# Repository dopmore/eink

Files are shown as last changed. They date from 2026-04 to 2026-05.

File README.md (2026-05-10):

Tiny e-reader

# Tiny-e-ink-Ebook-reader
This project aims to create a small portable e-reader, using an E-ink Display and a SD-card for storage.
It includes a Multi Directional Switch and a Select Button for inputs. While the MDS is for navigation (Next Page / Last Page), the select button is used to make a book mark and the middle button of the MDS then can be used to go back to the saved bookmark. 

I wanted to make this to be able to read books anywhere at any time without needing to carry around a big e-reader or get distracted by my phone :)!

## CAD / Assembly



The Assembly is easy as the case consists of only two parts that slide into each other and trap the PCB + Battery in between.

## PCB
eink2



The PCB will be soldered using a hotplate.

## Schematics


## PCB-order:


## Parts (LCSC):


## BOM
| Component | Link / Company | Price | Shipping | 
| ---- | ---- | ---- | ---- |
| PCB + Stencil | jlcpcb.com | $12.44 | free (coupon) |
| PCB-Parts  | lcsc.com | $15.42 | $8.95 |
| 103450 3,7 V 1500 mAh Polymer-Lithium-Akku jst PH 2,0 mm | https://www.aliexpress.com/item/1005009590723370.html | $7.60 | free |
| E-paper Screen 296x128 (GDEY029T94) | https://buy-lcd.com/products/29-inch-e-paper-screen-296x128-raspberry-pi-spi-display-gdey029t94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 | $7.91 | $10 |

Total: 62.32 (Incl. Shipping)

## Parts-Bom

| Index | LCSC# | MPN | Manufacturer | Package | Customer # | Description | RoHS | Quantity | MOQ | Multiple | Unit Price ($) | Extended Price ($) | Product Link |
| ----- | --- | --- | --- | --- | --- | --- | ---- | --- | --- | --- | --- | --- | --- |
| 1 | C325532 | RMC04022.21%N | TyoHM | 0402 | | 2.2Ω ±1% 62.5mW 0402 Thick Film Resistor | yes  | 100 | 100 | 100 | 0.0034 | 0.34 | [https://www.lcsc.com/product-detail/C325532.html](https://www.lcsc.com/product-detail/C325532.html) |
| 2 | C71911 | 16-213SDRC/S530-A3/TR8 | EVERLIGHT | 0402 | | Red 650nm LED Indication - Discrete 2V 0402 | yes  | 20 | 20  | 20 | 0.0330 | 0.66 | [https://www.lcsc.com/product-detail/C71911.html](https://www.lcsc.com/product-detail/C71911.html) |
| 3 | C77336 | MBR0530 | JSCJ | SOD-123 | | Diode 30V 500mA Surface Mount SOD-123 | yes  | 20 | 20  | 20 | 0.0332 | 0.66 | [https://www.lcsc.com/product-detail/C77336.html](https://www.lcsc.com/product-detail/C77336.html) |
| 4 | C7603347  | SI1308EDL | TECH PUBLIC | SOT-323 | | 30V 1.4A 360mW Surface Mount SOT-323 | yes  | 5 | 5 | 5 | 0.0840 | 0.42 | [https://www.lcsc.com/product-detail/C7603347.html](https://www.lcsc.com/product-detail/C7603347.html) |
| 5 | C52923 | CL05A105KA5NQNC | Samsung Electro-Mechanics | 0402 | | 1uF ±10% 25V Ceramic Capacitor X5R 0402 | yes  | 100 | 100 | 100 | 0.0040 | 0.40 | [https://www.lcsc.com/product-detail/C52923.html](https://www.lcsc.com/product-detail/C52923.html) |
| 6 | C511277 | MCP1700-3302E/TO | MICROCHIP | TO-92-3 | | 3.3V Positive Fixed TO-92-3 Voltage Regulators - Linear, Low Drop Out (LDO) Regulators RoHS | yes  | 1 | 1 | 1 | 0.8030 | 0.80 | [https://www.lcsc.com/product-detail/C511277.html](https://www.lcsc.com/product-detail/C511277.html) |
| 7 | C481407 | NX3225GA-12MHZ-STD-CRG-2 | NDK | SMD3225-4P | | Crystal 12MHz ±20ppm 8pF 100Ω SMD3225-4P | yes  | 5 | 5 | 5 | 0.2377 | 1.19 | [https://www.lcsc.com/product-detail/C481407.html](https://www.lcsc.com/product-detail/C481407.html) |
| 8 | C47647 | PH-2P | BOOMELE(Boom Precision Elec) | SMD,P=2mm,Surface Mount,Right Angle | | Connector Header 2 position 2mm Pitch Surface Mount, Right Angle | yes  | 12 | 12  | 12 | 0.0614 | 0.74 | [https://www.lcsc.com/product-detail/C47647.html](https://www.lcsc.com/product-detail/C47647.html) |
| 9 | C424093 | MCP73831T-2ACI/OT | MICROCHIP | SOT-23-5 | | 3.75V~6V Lithium Battery 1 550mA SOT-23-5 Battery Chargers ICs RoHS | yes  | 1 | 1 | 1 | 0.7611 | 0.76 | [https://www.lcsc.com/product-detail/C424093.html](https://www.lcsc.com/product-detail/C424093.html) |
| 10 | C4109 | 0402WGF2001TCE | UNI-ROYAL | 0402 | | 2kΩ ±1% 62.5mW 0402 Thick Film Resistor | yes  | 100 | 100 | 100 | 0.0008 | 0.08 | [https://www.lcsc.com/product-detail/C4109.html](https://www.lcsc.com/product-detail/C4109.html) |
| 11 | C410351 | TF-015 | Hanbo Electronic | SMD | | Micro SD card (TF card) Connector and Ejector Push-Push Surface Mount | yes  | 5 | 5 | 5 | 0.1383 | 0.69 | [https://www.lcsc.com/product-detail/C410351.html](https://www.lcsc.com/product-detail/C410351.html) |
| 12 | C388885 | EVQPUD02K | PANASONIC | SMD,4.7x4.5mm | | Tactile Switch SPST 2.2N 1.65mm J-Lead 4.7mm x 4.5mm Surface Mount, Right Angle | yes  | 5 | 5 | 5 | 0.2299 | 1.15 | [https://www.lcsc.com/product-detail/C388885.html](https://www.lcsc.com/product-detail/C388885.html) |
| 13 | C354600 | CKCS5020-47uH/M | CENKER | SMD,5x5mm | | 750mA 47uH ±20% 770mA 580mΩ Magnetic Shielded Inductor SMD,5x5mm Fixed Inductors RoHS | yes  | 10 | 10  | 10 | 0.0504 | 0.50 | [https://www.lcsc.com/product-detail/C354600.html](https://www.lcsc.com/product-detail/C354600.html) |
| 14 | C347476 | AO3401A | UMW | SOT-23 | | P-Channel 30V 4.2A 1.4W Surface Mount SOT-23 | yes  | 20 | 20  | 20 | 0.0321 | 0.64 | [https://www.lcsc.com/product-detail/C347476.html](https://www.lcsc.com/product-detail/C347476.html) |
| 15 | C11702 | 0402WGF1001TCE | UNI-ROYAL | 0402 | | 1kΩ ±1% 62.5mW 0402 Thick Film Resistor | yes  | 100 | 100 | 100 | 0.0011 | 0.11 | [https://www.lcsc.com/product-detail/C11702.html](https://www.lcsc.com/product-detail/C11702.html) |
| 16 | C318954 | TM-2011 | XKB Connection | SMD-5P,19.7x14.8mm | | SMD-5P,19.7x14.8mm Navigation Switches, Joystick RoHS | yes  | 5 | 5 | 5 | 0.2672 | 1.34 | [https://www.lcsc.com/product-detail/C318954.html](https://www.lcsc.com/product-detail/C318954.html) |
| 17 | C25905 | 0402WGF5101TCE | UNI-ROYAL | 0402 | | 5.1kΩ ±1% 62.5mW 0402 Thick Film Resistor | yes  | 100 | 100 | 100 | 0.0009 | 0.09 | [https://www.lcsc.com/product-detail/C25905.html](https://www.lcsc.com/product-detail/C25905.html) |
| 18 | C25744 | 0402WGF1002TCE | UNI-ROYAL | 0402 | | 10kΩ ±1% 62.5mW 0402 Thick Film Resistor | yes  | 100 | 100 | 100 | 0.0013 | 0.13 | [https://www.lcsc.com/product-detail/C25744.html](https://www.lcsc.com/product-detail/C25744.html) |
| 19 | C25100 | 0402WGF270JTCE | UNI-ROYAL | 0402 | | 27Ω ±1% 62.5mW 0402 Thick Film Resistor | yes  | 100 | 100 | 100 | 0.0008 | 0.08 | [https://www.lcsc.com/product-detail/C25100.html](https://www.lcsc.com/product-detail/C25100.html) |
| 20 | C2456208  | W25Q16JVZPIQ TR | Winbond | WSON-8-EP(5x6) | | 2.7V~3.6V 16Mbit 133MHz SPI WSON-8-EP(5x6) Memory (ICs) RoHS | yes  | 1 | 1 | 1 | 1.2904 | 1.29 | [https://www.lcsc.com/product-detail/C2456208.html](https://www.lcsc.com/product-detail/C2456208.html) |
| 21 | C23733 | CL05A475MP5NRNC | Samsung Electro-Mechanics | 0402 | | 4.7uF ±20% 10V Ceramic Capacitor X5R 0402 | yes  | 50 | 50  | 50 | 0.0059 | 0.30 | [https://www.lcsc.com/product-detail/C23733.html](https://www.lcsc.com/product-detail/C23733.html) |
| 22 | C2040 | RP2040 | Raspberry Pi | LQFN-56(7x7) | | 133MHz 30 LQFN-56(7x7) Microcontrollers RoHS | yes  | 1 | 1 | 1 | 0.9482 | 0.95 | [https://www.lcsc.com/product-detail/C2040.html](https://www.lcsc.com/product-detail/C2040.html) |
| 23 | C19702 | CL10A106KP8NNNC | Samsung Electro-Mechanics | 0603 | | 10uF ±10% 10V Ceramic Capacitor X5R 0603 | yes  | 50 | 50  | 50 | 0.0080 | 0.40 | [https://www.lcsc.com/product-detail/C19702.html](https://www.lcsc.com/product-detail/C19702.html) |
| 24 | C19077718 | FPC-0.5FX-24PH20 | Yuandi | SMD,P=0.5mm | | FFC/FPC Connector 24 Position 0.5mm Pitch Bottom Contact | yes  | 5 | 5 | 5 | 0.0927 | 0.46 | [https://www.lcsc.com/product-detail/C19077718.html](https://www.lcsc.com/product-detail/C19077718.html) |
| 25 | C165948 | TYPE-C-31-M-12 | Korean Hroparts Elec | SMD | | USB-C (USB TYPE-C) Receptacle Connector 16 Position Surface Mount | yes  | 5 | 5 | 5 | 0.1701 | 0.85 | [https://www.lcsc.com/product-detail/C165948.html](https://www.lcsc.com/product-detail/C165948.html) |
| 26 | C1562 | 0402CG330J500NT | FH | 0402 | | 33pF ±5% 50V Ceramic Capacitor C0G 0402 | yes  | 100 | 100 | 100 | 0.0013 | 0.13 | [https://www.lcsc.com/product-detail/C1562.html](https://www.lcsc.com/product-detail/C1562.html) |
| 27 | C1525 | CL05B104KO5NNNC | Samsung Electro-Mechanics | 0402 | | 100nF ±10% 16V Ceramic Capacitor X7R 0402 | yes  | 100 | 100 | 100 | 0.0013 | 0.13 | [https://www.lcsc.com/product-detail/C1525.html](https://www.lcsc.com/product-detail/C1525.html) |

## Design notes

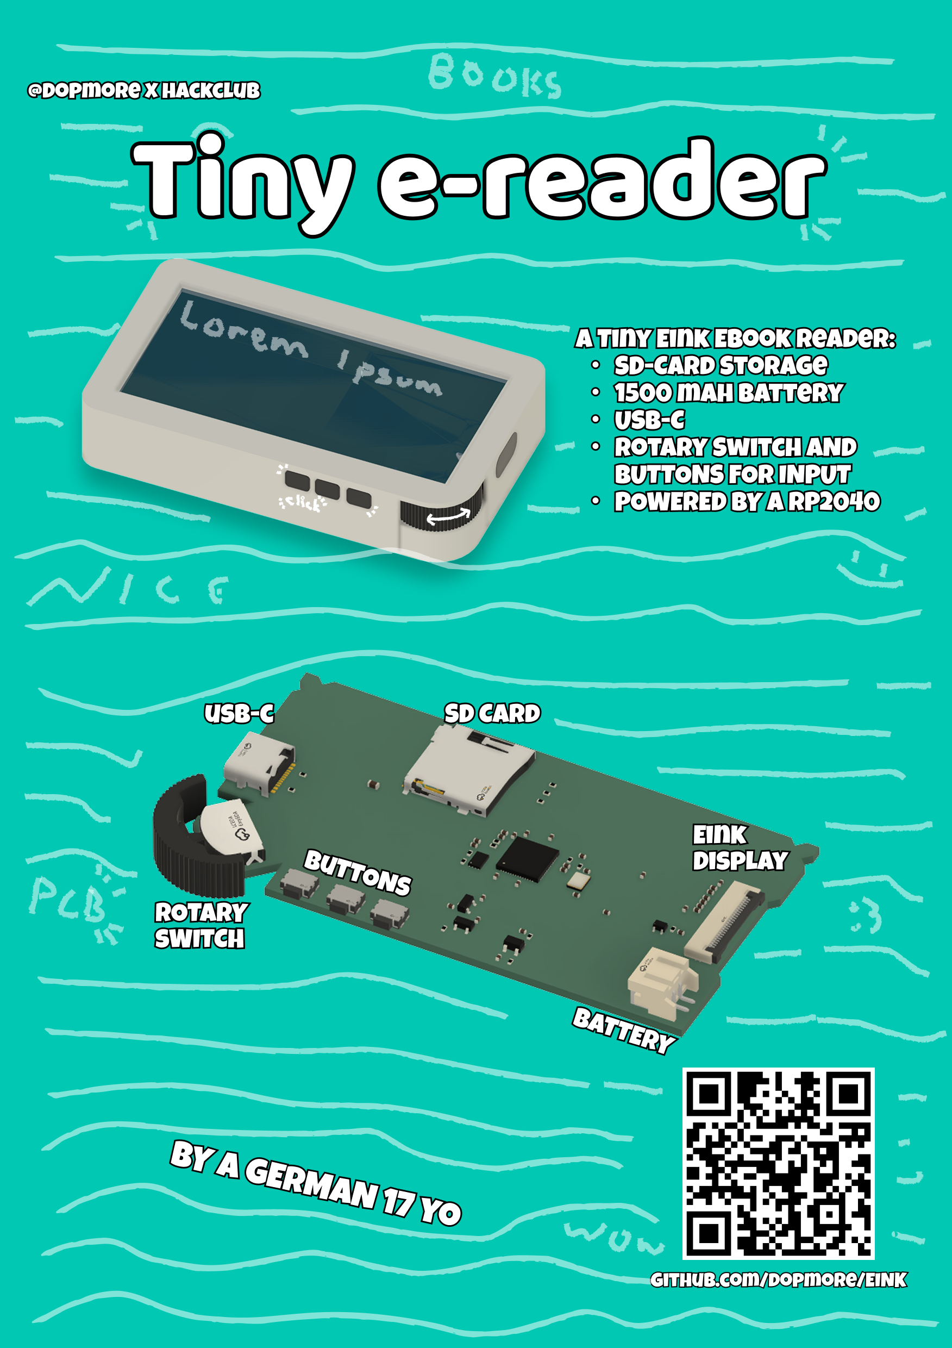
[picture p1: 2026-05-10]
Tiny e-reader.png

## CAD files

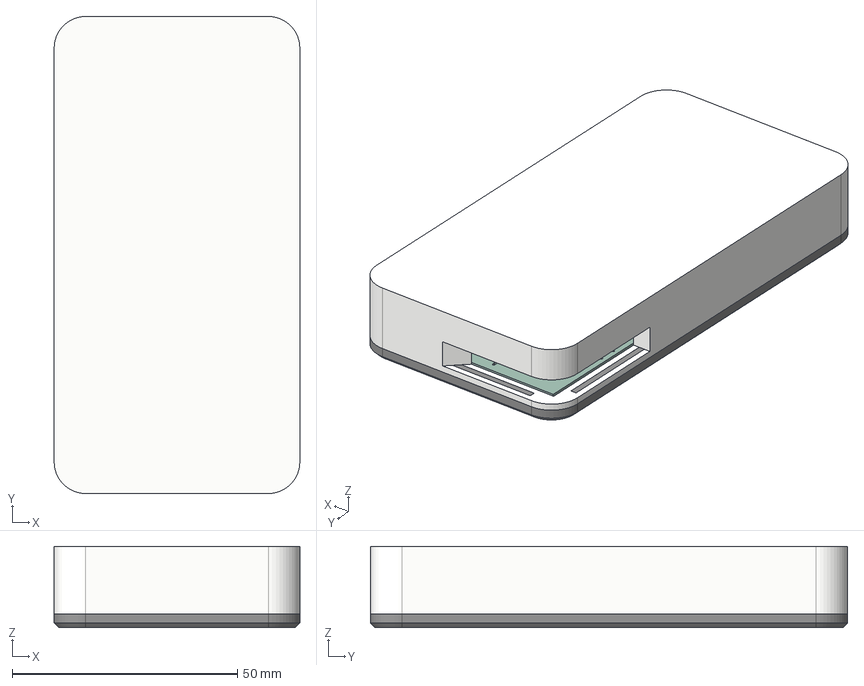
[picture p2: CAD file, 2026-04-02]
CAD/EinkAssembly.step
54.6 x 106.0 x 18.0 mm
SOT-23-5
SOT-23 x 2
C_0402_1005Metric x 30
R_0402_1005Metric x 17
Winbond_USON-8-1EP_3x2mm_P0.5mm_EP0.2x1.6mm
SW_SPST_TS-1088-xR020 x 2
JST_EH_S2B-EH_1x02_P2.50mm_Horizontal
Crystal_SMD_3225-4Pin_3.2x2.5mm
QFN-56-1EP_7x7mm_P0.4mm_EP3.2x3.2mm
C_0603_1608Metric
microSD_HC_Hirose_DM3D-SF
SOT-323_SC-70
eink_PCB

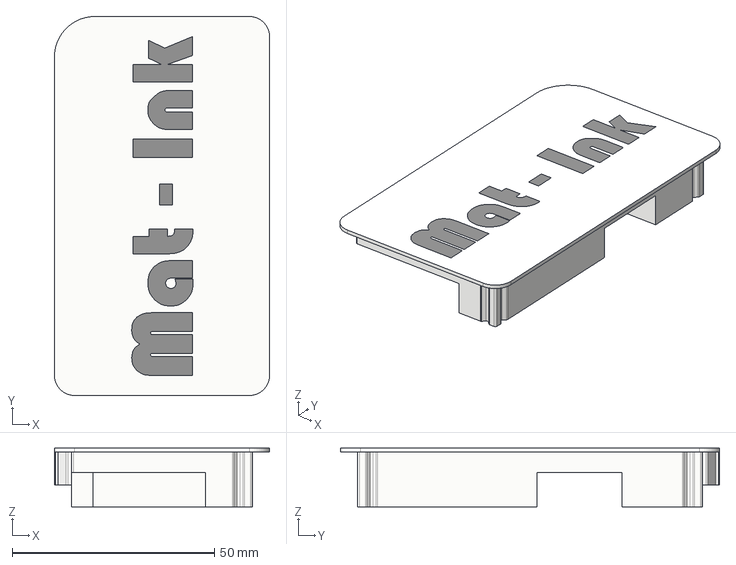
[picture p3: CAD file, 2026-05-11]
CAD/EinkTopCase.step
53.2 x 93.7 x 14.5 mm

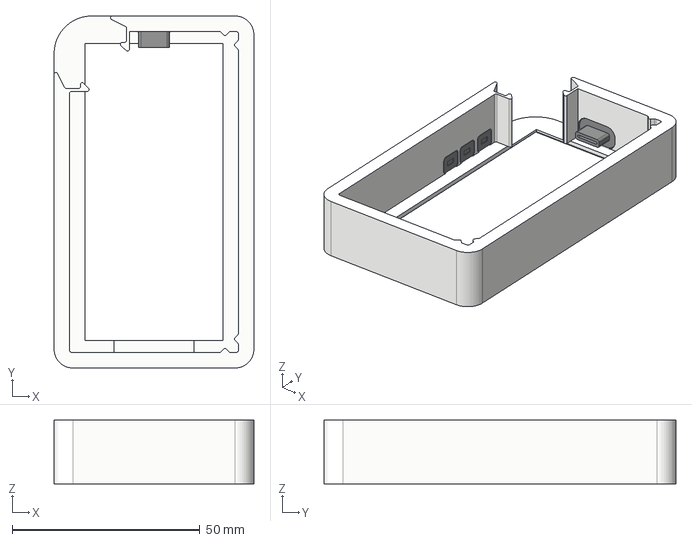
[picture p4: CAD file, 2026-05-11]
CAD/EinkBottomCase.step
53.2 x 93.7 x 17.0 mm

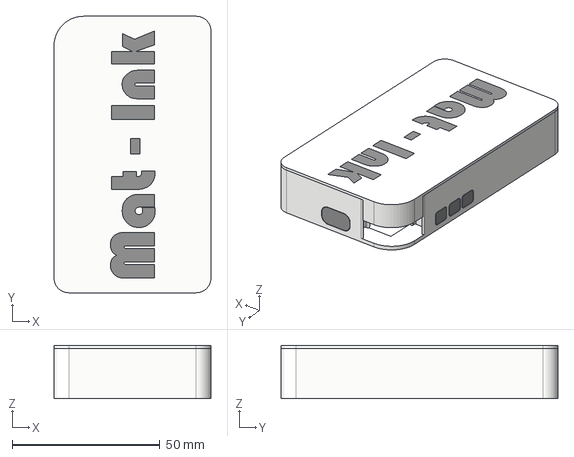
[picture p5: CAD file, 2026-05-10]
CAD/Generic-EinkCasePrint.step
53.2 x 93.7 x 18.0 mm

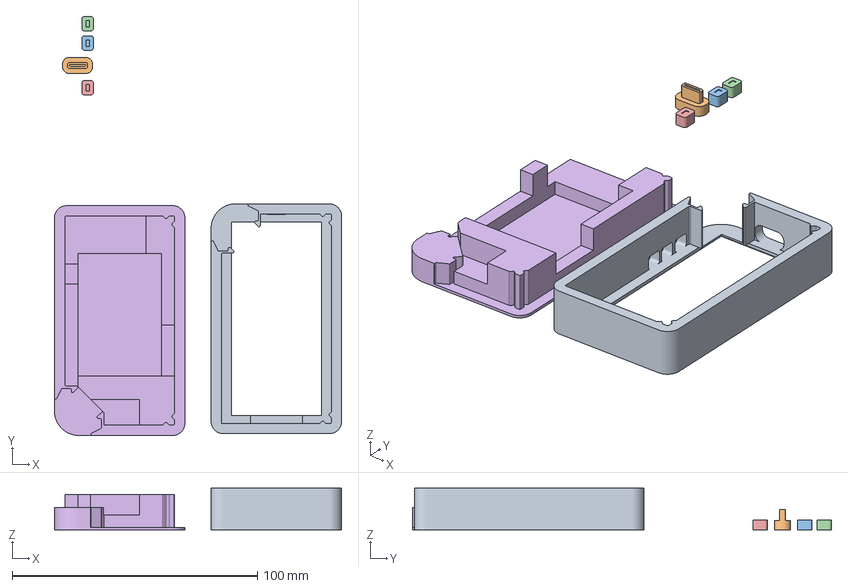
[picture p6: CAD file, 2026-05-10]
CAD/BambuLab-EinkCasePrint.3mf
117.1 x 170.8 x 17.0 mm
Sub-merged body

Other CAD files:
CAD/EinkAssembly.f3z

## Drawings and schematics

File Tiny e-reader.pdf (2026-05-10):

# Tiny e-reader

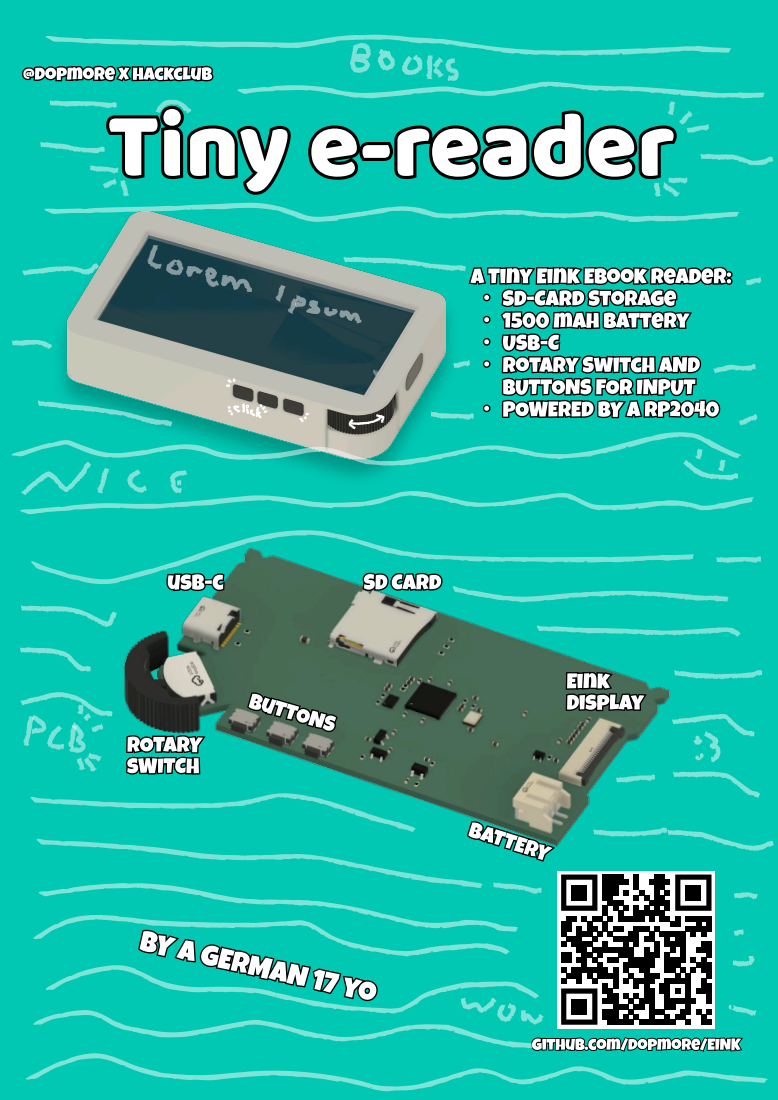
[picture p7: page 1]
@dopmore x hackclub; usb-c; SD Card; rOTARY sWITCH; buTTONS; Eink Display; BATTERY

a Tiny Eink Ebook Reader:
SD-Card Storage
1500 mah Battery
USB-C
Rotary Switch aND
BUTTONS FOR INPUT
POWERED BY A rP2040

bY A gERMAN 17 yo

github.com/dopmore/EINK

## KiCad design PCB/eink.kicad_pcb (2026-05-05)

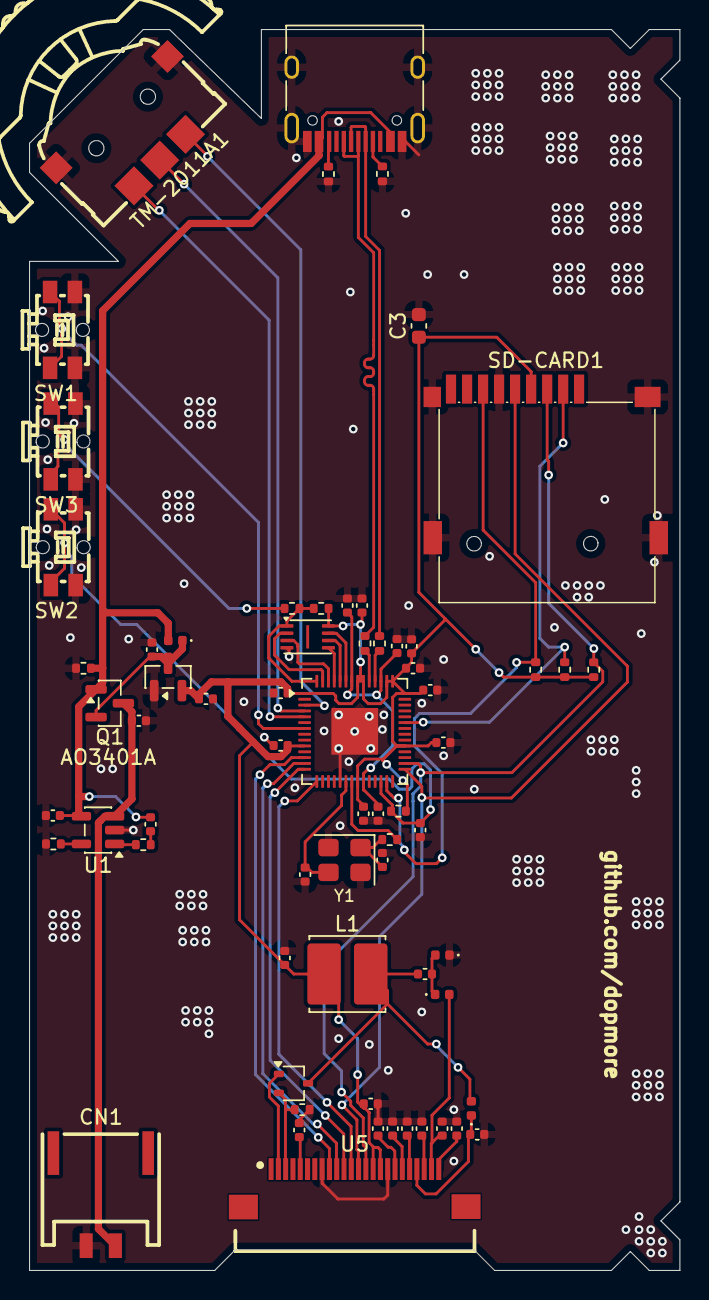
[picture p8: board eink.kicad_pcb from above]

Board: 2 copper layers, 44.6 x 85.1 mm, 66 parts (0 on the bottom side), 50 nets.

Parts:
C1, C2, C20, C21: 4.7uF; C_0402_1005Metric
C3: 10uF; C_0603_1608Metric
C4, C6, C7, C10, C22, C23, C24, C25, C26, C27, C28, C29, C30: 1uF; C_0402_1005Metric
C5, C8, C9, C11, C12, C15, C16, C17, C18, C19: 0.1uF; C_0402_1005Metric
C13, C14: 33pF; C_0402_1005Metric
CN1: Battery; CONN-SMD_2P-P2.00_PH2.0-SPWB
D1: LED; C_0402_1005Metric
D2, D3, D4, D5: MBR0530; D_0402_1005Metric
J1: USB_C_Receptacle_USB2.0_14P; USB_C_Receptacle_HRO_TYPE-C-31-M-12
L1: 47uH; L_Cenker_CKCS5020
Q1: AO3401A; SOT-23
Q2: Si1308EDL; SOT-323_SC-70
R1, R2: 5.1K; R_0402_1005Metric
R3, R4, R5, R8, R11, R13: 10K; R_0402_1005Metric
R6, R12, R14: 1K; R_0402_1005Metric
R7: 2k; R_0402_1005Metric
R9, R10: 27; R_0402_1005Metric
R15: 2.2; R_0402_1005Metric
SD-CARD1: TF-SMD_TF-015
SW1, SW2, SW3: SW-SMD_EVQPUD02K-1
TM-2011A1: Multi-Directional Switch; SW-SMD_TM-2011
U1: MCP73831-2-OT; SOT-23-5
U2: MCP1700x-300xxTT; SOT-23
U3: RP2040; QFN-56-1EP_7x7mm_P0.4mm_EP3.2x3.2mm
U4: W25Q16JVZPIQ TR; Winbond_USON-8-1EP_3x2mm_P0.5mm_EP0.2x1.6mm
U5: FPC-SMD_24P-P0.50_YUANDI_FPC-0.5FX-24PH20
Y1: 12 MHz; Crystal_SMD_3225-4Pin_3.2x2.5mm

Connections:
+1V1: C6.1, C8.1, C9.1, U3.23 (DVDD), U3.45 (VREG_VOUT), U3.50 (DVDD)
+3.3V: C3.1, C7.1, C10.1, C11.1, C12.1, C15.1, C16.1, C17.1, C18.1, C19.1, C20.1, C23.1, L1.1, R3.1, R4.1, R5.1, R11.1, R13.1, SD-CARD1.4 (VDD), U2.2 (VO), U3.1 (IOVDD), U3.10 (IOVDD), U3.22 (IOVDD), U3.33 (IOVDD), U3.42 (IOVDD), U3.43 (ADC_AVDD), U3.44 (VREG_IN), U3.48 (USB_VDD), U3.49 (IOVDD), U4.8 (VCC), U5.15 (VDDIO), U5.16 (VCI)
/D/C: U3.14 (GPIO11), U5.11 (D/C)
/Eink BUSY: U3.12 (GPIO9), U5.9 (BUSY)
/Eink CS: U3.15 (GPIO12), U5.12 (CS)
/Eink RST: U3.13 (GPIO10), U5.10 (RES)
/GDR: Q2.1 (G), U5.2 (GDR)
/PREVGH: C22.1, D5.1 (K), U5.21 (VGH)
/PREVGL: C28.1, D3.2 (A), U5.23 (VGL)
/RESE: Q2.2 (S), R15.1, U5.3 (RESE)
GND: C1.2, C2.2, C3.2, C4.2, C5.1, C6.2, C7.2, C8.2, C9.2, C10.2, C11.2, C12.2, C13.1, C14.1, C15.2, C16.2, C17.2, C18.2, C19.2, C20.2, C22.2, C23.2, C24.2, C25.2, C26.2, C27.2, C28.2, C29.2, C30.2, CN1.2, D4.1 (K), J1.A1 (GND), J1.A12 (GND), J1.B1 (GND), J1.B12 (GND), J1.S1 (SHIELD), R1.1, R2.1, R7.2, R8.2, R15.2, SD-CARD1.6 (VSS), SD-CARD1.10 (GND), SD-CARD1.11 (GND), SD-CARD1.12 (GND), SD-CARD1.13 (GND), SW1.1, SW1.3, SW2.1, SW2.3, SW3.1, SW3.3, TM-2011A1.a, TM-2011A1.e, U1.2 (V_{SS}), U2.1 (GND), U3.19 (TESTEN), U3.57 (GND), U4.4 (GND), U5.8 (BS), U5.17 (VSS), Y1.2, Y1.4
GPIO1: TM-2011A1.b, U3.3 (GPIO1)
GPIO2: TM-2011A1.c, U3.4 (GPIO2)
GPIO3: TM-2011A1.d, U3.5 (GPIO3)
GPIO5: SW1.2, SW1.4, U3.7 (GPIO5)
GPIO16: R3.2, SD-CARD1.7 (DAT0(D0)), U3.27 (GPIO16)
GPIO18: SD-CARD1.5 (CLK(SCLK)), U3.29 (GPIO18), U5.13 (SCLK)
GPIO19: R5.2, SD-CARD1.3 (CMD(DI)), U3.30 (GPIO19), U5.14 (SDI)
GPIO25: R4.2, SD-CARD1.2 (CDDAT3(CS)), U3.37 (GPIO25)
unnamed: C14.2, R14.1, Y1.1
unnamed: D1.1 (K), R6.1
unnamed: C4.1, D2.1 (K), Q1.2 (S), U2.3 (VI)
unnamed: C21.1, D3.1 (K), D4.2 (A)
unnamed: C21.2, D5.2 (A), L1.2, Q2.3 (D)
unnamed: J1.A5 (CC1), R1.2
unnamed: J1.B5 (CC2), R2.2
unnamed: C2.1, CN1.1, Q1.3 (D), U1.3 (V_{BAT})
unnamed: R12.2, SW3.2, SW3.4
unnamed: R7.1, U1.5 (PROG)
unnamed: R6.2, U1.1 (STAT)
unnamed: C5.2, R11.2, SW2.2, SW2.4, U3.26 (RUN)
unnamed: R10.2, U3.46 (USB_DM)
unnamed: R9.2, U3.47 (USB_DP)
unnamed: C30.1, U5.24 (VCOM)
unnamed: C24.1, U5.18 (VDD)
unnamed: C25.1, U5.19 (VPP)
unnamed: C26.1, U5.20 (VSH1)
unnamed: C29.1, U5.5 (VSH2)
unnamed: C27.1, U5.22 (VSL)
QSPI_SCLK: U3.52 (QSPI_SCLK), U4.6 (CLK)
QSPI_SD0: U3.53 (QSPI_SD0), U4.5 (DI/IO_{0})
QSPI_SD1: U3.55 (QSPI_SD1), U4.2 (DO/IO_{1})
QSPI_SD2: U3.54 (QSPI_SD2), U4.3 (~WP/IO_{2})
QSPI_SD3: U3.51 (QSPI_SD3), U4.7 (~HOLD/~RESET/IO_{3})
QSP_SS: R12.1, R13.2, U3.56 (QSPI_SS), U4.1 (~CS)
USB_D+: J1.A6 (D+), J1.B6 (D+), R9.1
USB_D-: J1.A7 (D-), J1.B7 (D-), R10.1
VBUS: C1.1, D1.2 (A), D2.2 (A), J1.A4 (VBUS), J1.A9 (VBUS), J1.B4 (VBUS), J1.B9 (VBUS), Q1.1 (G), R8.1, U1.4 (V_{DD})
XIN: C13.2, U3.20 (XIN), Y1.3
XOUT: R14.2, U3.21 (XOUT)

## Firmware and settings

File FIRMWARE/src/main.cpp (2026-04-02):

#include <Arduino.h>

#define ENABLE_GxEPD2_GFX

#include <Adafruit_TinyUSB.h>
#include <Adafruit_GFX.h>
#include <GxEPD2_BW.h>
#include <Fonts/FreeMonoBold9pt7b.h>
#include <Fonts/FreeMonoBold12pt7b.h>
#include <SPI.h>
#include <SdFat.h>

// Using SDIO
SdFat SD;

File32 file; // current Ebook file
File32 root; // root dir

// USB Mass Storage (MSC)
Adafruit_USBD_MSC usb_msc;

#define PIN_SD_DAT0 22 // DAT0-3: GPIO22 - GPIO25
#define PIN_SD_SCK 20
#define PIN_SD_CMD 21

#define SD_CONFIG SdioConfig(PIN_SD_SCK, PIN_SD_CMD, PIN_SD_DAT0)

#define EPD_BUSY 9
#define EPD_RST 10
#define EPD_DC 11
#define EPD_CS 12
#define EPD_CLK 18
#define EPD_MOSI 19

arduino::MbedSPI EPD_SPI(-1, EPD_MOSI, EPD_CLK);

GxEPD2_BW<GxEPD2_290_GDEY029T94, GxEPD2_290_GDEY029T94::HEIGHT> display(GxEPD2_290_GDEY029T94(EPD_CS, EPD_DC, EPD_RST, EPD_BUSY));

// Inputs
#define MDS_RIGHT 1
#define MDS_LEFT 2
#define MDS_CENTER 3
#define SELECT 5

int32_t msc_read_cb(uint32_t lba, void *buffer, uint32_t bufsize);
int32_t msc_write_cb(uint32_t lba, uint8_t *buffer, uint32_t bufsize);
void msc_flush_cb(void);

void print_rootdir(File32 *rdir);

bool is_mounted; // avoid unneccesary checks
bool msc_ready;

int start = 0;     // starting idx of the text
bool npage = true; // new page accessed
char textbuffer[100];
int textlen = 100;
int bookmark = 0;

void setup()
{
  Serial.begin(115200);
  delay(1000);

  display.epd2.selectSPI(EPD_SPI, SPISettings(4000000, MSBFIRST, SPI_MODE0));
  display.init(115200);

  // Inputs
  pinMode(MDS_RIGHT, INPUT_PULLUP);
  pinMode(MDS_LEFT, INPUT_PULLUP);
  pinMode(MDS_CENTER, INPUT_PULLUP);
  pinMode(SELECT, INPUT_PULLUP);

  // setting up SD card
  if (!SD.begin(SD_CONFIG))
  {
    SD.initErrorHalt(&Serial);
  }
  Serial.println("SDcard Initialized successfully!");
  // Seting up the SD card as a Mass Storage Device

  usb_msc.setID("Dopmore", "SD-Card", "1.00");
  usb_msc.setReadWriteCallback(msc_read_cb, msc_write_cb, msc_flush_cb);
  usb_msc.setUnitReady(false);
  usb_msc.begin();
  // re-enumeration
  if (TinyUSBDevice.mounted())
  {
    TinyUSBDevice.detach();
    delay(10);
    TinyUSBDevice.attach();
  }
  delay(100);
  // SD Card size

  uint32_t block_count = SD.card()->sectorCount();
  Serial.print("Volume size (MB):  ");
  Serial.println((block_count / 2) / 1024);

  usb_msc.setCapacity(block_count, 512);

  root = SD.open("/"); // list files
  print_rootdir(root);
}

void loop()
{
  is_mounted = TinyUSBDevice.mounted();
  if (is_mounted)
  {
    msc_ready = true;
    usb_msc.setUnitReady(true);
    Serial.println("MSC mode enabled");
  }
  else
  {
    if (msc_ready)
    { // skip if msc is already turned off
      msc_ready = false;
      usb_msc.setUnitReady(false);
      Serial.println("MSC mode disabled");
    }
    if (SD.exists("book.txt"))
    {
      file = SD.open("book.txt");
    }

    if (npage)
    { // only refresh if a new page has been accessed
      if (start > file.size())
      {
        start = 0;
      }
      else if (start < 0)
      {
        start = file.size() - textlen;
      }
      display.clearScreen();
      display.setCursor(0, 0);
      display.setTextColor(GxEPD_BLACK);

      // go to current Position and write the next [max chars] that fit on the screen
      file.seek(start);
      start = file.position() - textlen; // stay at current position
      file.fgets(textbuffer, textlen);
      display.print(textbuffer);
      display.display();
      npage = false;
    }

    if (!digitalRead(MDS_LEFT))
    { // next page
      npage = true;
      start = start + textlen;
    }
    if (!digitalRead(MDS_RIGHT))
    { // last page
      npage = true;
      npage = true;
      start = start - textlen;
    }
    if (!digitalRead(MDS_CENTER))
    { // make a bookmark
      bookmark = start;
    }
    if (!digitalRead(SELECT))
    { // access bookmark
      npage = true;
      start = bookmark;
    }
  }
}

void print_rootdir(File32 &rdir)
{
  File32 file;
  while (file.openNext(&rdir, O_RDONLY))
  { // read only
    display.println(file.name());

    if (file.isDir())
    {
      display.write("/");
    }
    else
    {
      display.write(file.size()); // show file size if it is a file
    }

    display.println();
    file.close();
  }
}

// READ/WRITE functions for the MSC mode

// Refer to: https://github.com/adafruit/Adafruit_TinyUSB_Arduino/blob/master/examples/MassStorage/msc_sdfat/msc_sdfat.ino

// Callback invoked when received READ10 command.
// Copy disk's data to buffer (up to bufsize) and
// return number of copied bytes (must be multiple of block size)
int32_t msc_read_cb(uint32_t lba, void *buffer, uint32_t bufsize)
{
  bool rc = SD.card()->readSectors(lba, (uint8_t *)buffer, bufsize / 512);
  return rc ? bufsize : -1;
}

// Callback invoked when received WRITE10 command.
// Process data in buffer to disk's storage and
// return number of written bytes (must be multiple of block size)

int32_t msc_write_cb(uint32_t lba, uint8_t *buffer, uint32_t bufsize)
{
#ifdef LED_BUILTIN
  digitalWrite(LED_BUILTIN, HIGH);
#endif
  bool rc = SD.card()->writeSectors(lba, buffer, bufsize / 512);
  return rc ? bufsize : -1;
}

// Callback invoked when WRITE10 command is completed (status received and accepted by host).
// used to flush any pending cache.
void msc_flush_cb(void)
{
  SD.card()->syncDevice();
  SD.cacheClear(); // clear file system's cache to force refresh
}

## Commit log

2026-04-02 Added Gerbers
2026-04-02 Add BOM and pos
    [eink.csv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]
2026-04-02 Enhance README with project details and visuals
    Expanded project description and added sections for CAD, PCB, and Schematics with images.
2026-05-04 Add PCBA section and image to README
    Added PCBA section with image to README.
2026-05-05 Revise PCB section and add BOM details
    Updated PCB section and added BOM table with components and prices.
2026-05-05 Add BOM.csv with component details and pricing
    [BOM.csv]
2026-05-05 Update total cost in BOM section
    Updated total cost in BOM section to reflect new prices.
2026-05-05 Add new entries to BOM.csv
    [BOM.csv]
2026-05-05 Modify shipping details for PCB and Stencil
    Updated shipping information for PCB and Stencil in BOM.
2026-05-05 Enhance README with assembly and PCB information
    Added details about assembly and PCB soldering process.
2026-05-10 Add parts BOM section to README
    Added a detailed parts bill of materials (BOM) section with specifications, quantities, and links for various components.
2026-05-10 Add header and update BOM.csv entries
    Added header row and updated BOM entries.
    [BOM.csv]
